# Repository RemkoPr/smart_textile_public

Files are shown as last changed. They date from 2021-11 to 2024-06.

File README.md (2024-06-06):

# Smart Textile [public repo]

This repo contains a manufaturing guide of and code for the smart textile featured in the MDPI paper [Modular Piezoresistive Smart Textile for State Estimation of Cloths](https://doi.org/10.3390/s22010222). Data obtained during the experiments outlined in this paper can be found on [Zenodo](https://doi.org/10.5281/zenodo.5718426).

Further information in README's in the subfolders.

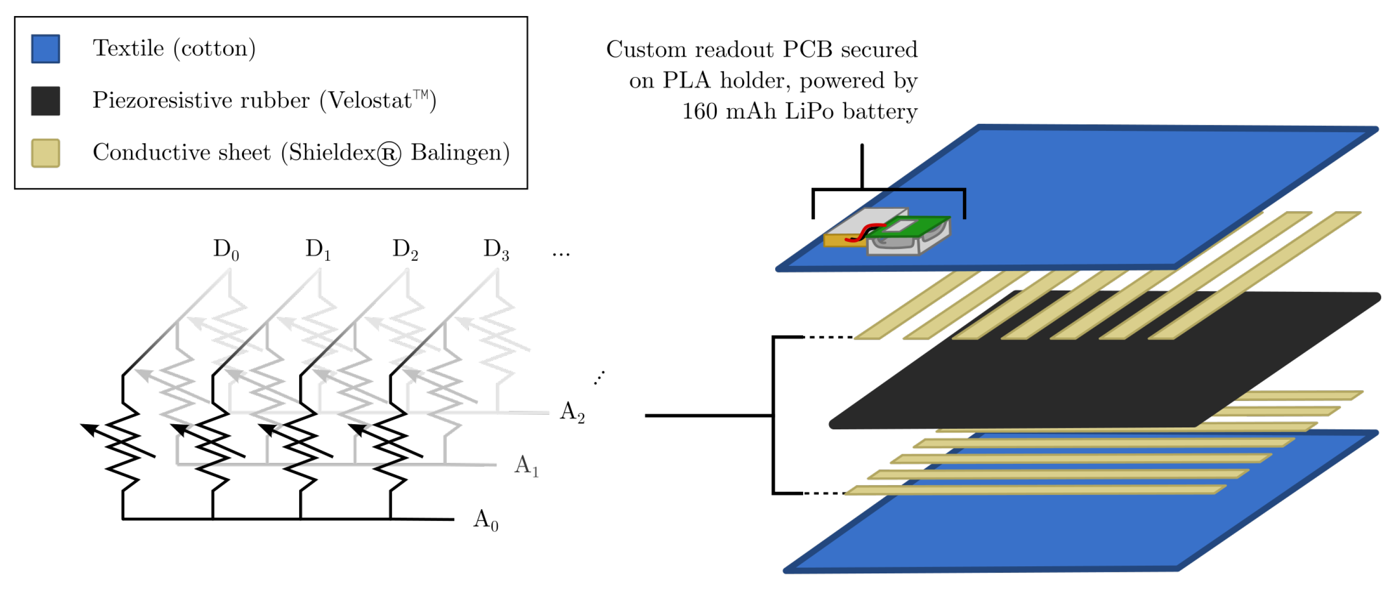
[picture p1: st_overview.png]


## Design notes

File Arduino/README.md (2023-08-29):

# Flashing the firmware

First, the smart textile PCB board must be installed to the Arduino IDE. Do this by installing the [IDLab-AIRO Boards package](https://github.com/RemkoPr/airo-nrf52840-boards/tree/main).

Once the Arduino IDE can compile sketches for the smart textile PCB, open pcb_firmware.ino and export a compiled binary.
Flashing of the PCB is done through the serial wire debug (SWD) protocol using a [JLink EDU Mini](https://www.segger.com/products/debug-probes/j-link/models/j-link-edu-mini/).
When flashing, it is recommended to use .hex files, so that you don't have to worry about the start address. Should this not be possible, use .bin files.
When reflashing the [bootloader](https://github.com/arduino/ArduinoCore-mbed/tree/master/bootloaders/nano33ble) using a .bin file, do this at address 0x00000000.
When only flashing a compiled sketch using a .bin file, do this at address 0x00010000.

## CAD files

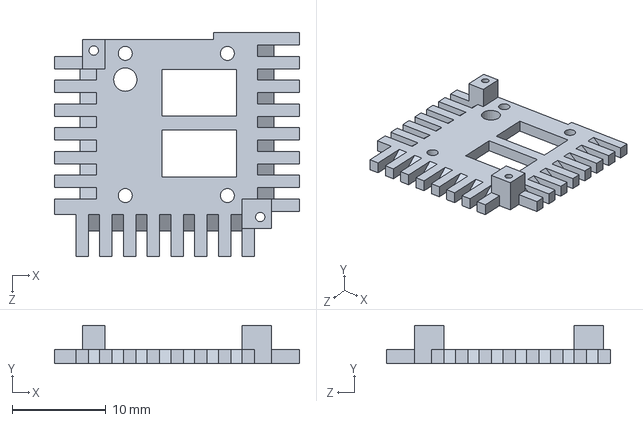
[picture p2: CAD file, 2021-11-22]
Solidworks/pcb_holder_mirrored.SLDPRT
26.2 x 4.10 x 23.9 mm

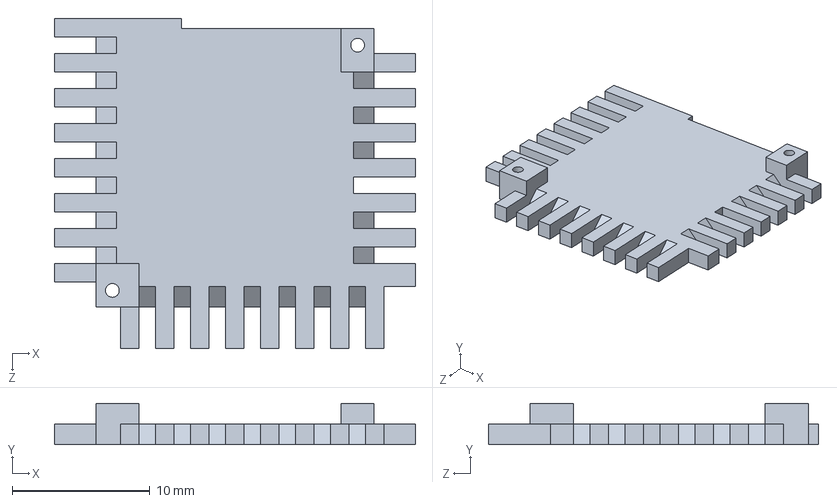
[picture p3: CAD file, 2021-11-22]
Solidworks/pcb_holder.SLDPRT
26.2 x 3.00 x 23.9 mm

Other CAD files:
Solidworks/pcb_holder.STL
Solidworks/pcb_holder_mirrored.STL

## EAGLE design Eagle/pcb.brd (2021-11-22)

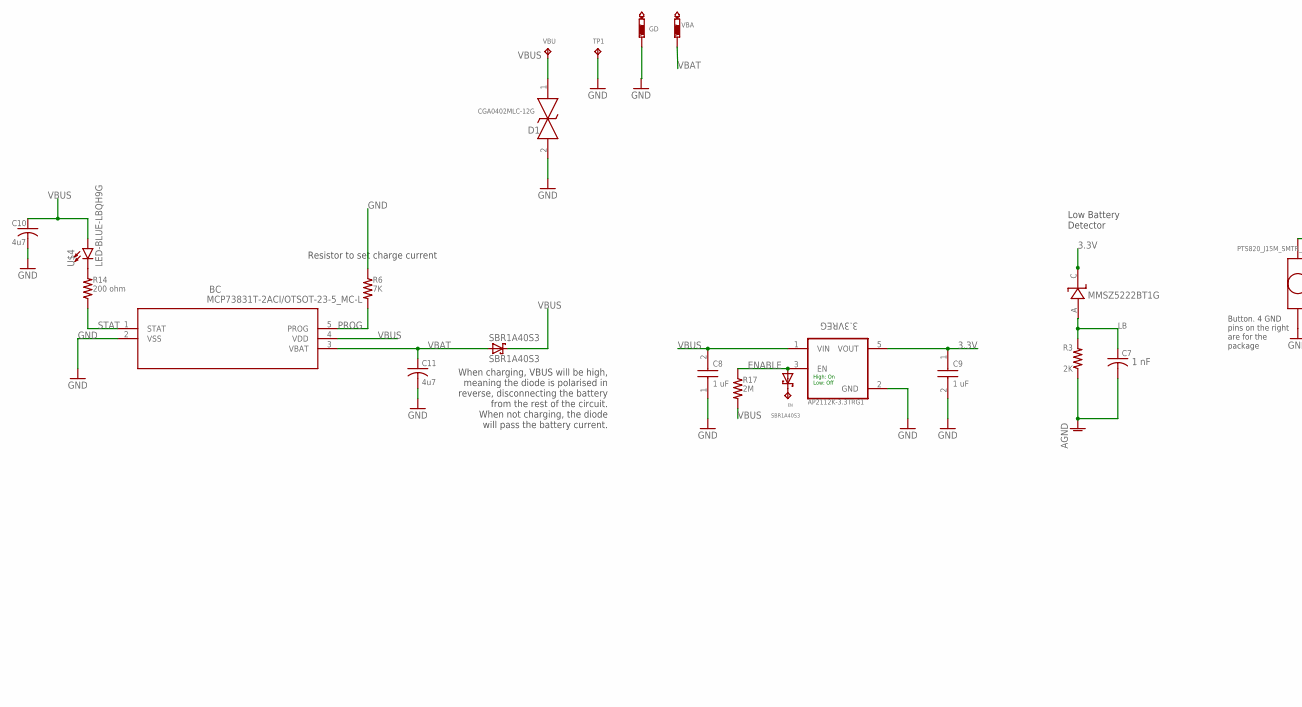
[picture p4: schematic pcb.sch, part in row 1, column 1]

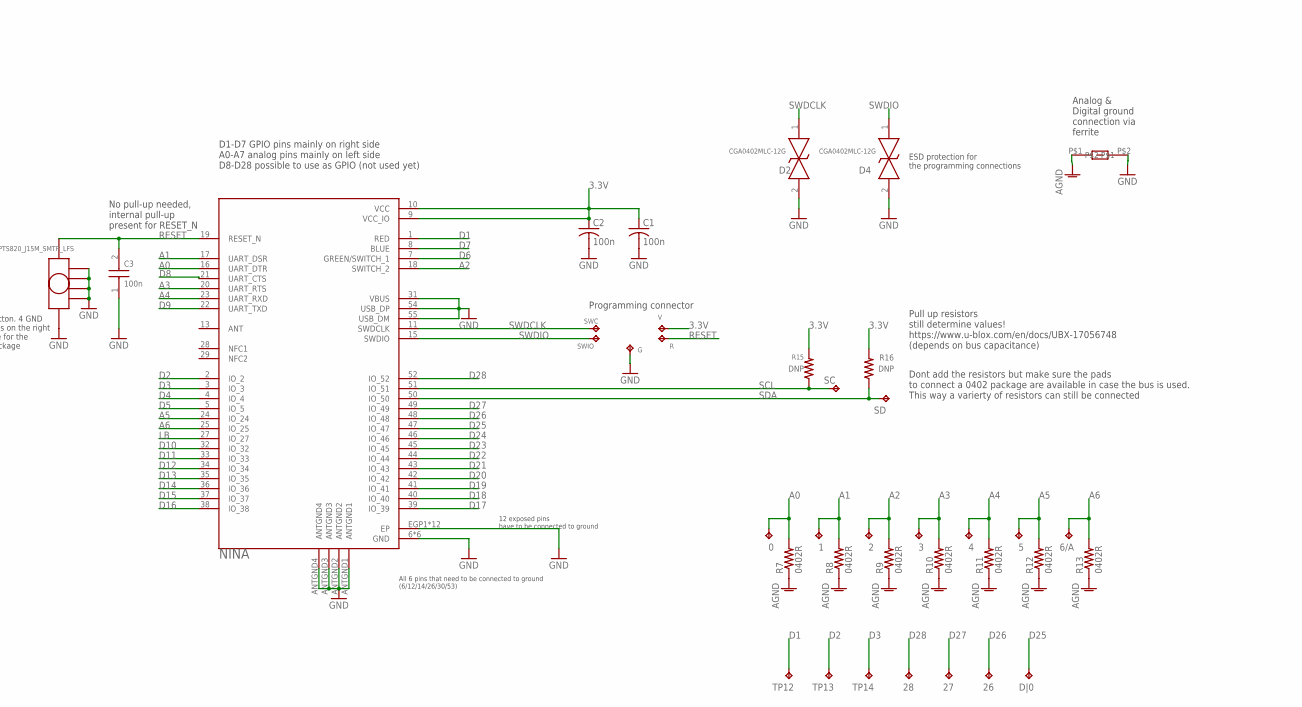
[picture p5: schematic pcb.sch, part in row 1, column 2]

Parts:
0, 1, 2, 3, 4, 5, 6/A, 26, 27, 28: CUSTOM_HOLE1; CUSTOM_HOLE
3.3VREG: AP2112K-3.3TRG1; SOT95P285X140-5N
BC: MCP73831T-2ACI/OTSOT-23-5_MC-L; SOT-23-5_MC-L
BUTTON: PTS820_J15M_SMTR_LFS; PTS820_J15
C1, C2: 100n; C0402
C3: 100n; CAPC1005X33N
C7: 1 nF; C0402
C8, C9: 1 uF; CAPC1005X33N
C10, C11: 4u7; C0402
D1, D2, D4: CGA0402MLC-12G; CGA0402MLC12G
D|0: CUSTOM_HOLE1; CUSTOM_HOLE
EN: CUSTOM_HOLE1; CUSTOM_HOLE
G: TPB1,27; B1,27
GD: PTR1TP18R; TP18R
MMSZ5222BT1G: MMSZ5222BT1G; SOD−123
R: TPB1,27; B1,27
R3: 2K; RESC1005X40N
R6: 7K; RESC1005X40N
R7, R8, R9, R10, R11, R12, R13: 0402R; RESC1005X40N
R14: 200 ohm; RESC1005X40N
R15, R16: DNP; RESC1005X40N
R17: 2M; RESC1005X40N
SBR1A40S3: SBR1A40S3; SOD323
SC: CUSTOM_HOLE1; CUSTOM_HOLE
SD: CUSTOM_HOLE1; CUSTOM_HOLE
SWC: TPB1,27; B1,27
SWIO: TPB1,27; B1,27
TP1, TP12, TP13, TP14: CUSTOM_HOLE1; CUSTOM_HOLE
U1: NINA; XCVR_NINA-B306
U$2: SBR1A40S3; SOD323
U$4: LED-BLUE-LBQH9G; LBQH9G-0402
U$5: BLM18KG121WH1D; 0603
V: TPB1,27; B1,27
VBA: PTR1TP18R; TP18R
VBU: CUSTOM_HOLE1; CUSTOM_HOLE

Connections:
3.3V: 3.3VREG.5 (VOUT), C1.1, C2.1, C9.1, MMSZ5222BT1G.C, R15.2, R16.2, U1.9 (VCC_IO), U1.10 (VCC), V.TP
A0: 0.P$1, R7.2, U1.16 (UART_DTR)
A1: 1.P$1, R8.2, U1.17 (UART_DSR)
A2: 2.P$1, R9.2, U1.18 (SWITCH_2)
A3: 3.P$1, R10.2, U1.20 (UART_RTS)
A4: 4.P$1, R11.2, U1.23 (UART_RXD)
A5: 5.P$1, R12.2, U1.24 (IO_24)
A6: 6/A.P$1, R13.2, U1.25 (IO_25)
AGND: C7.2, R3.1, R7.1, R8.1, R9.1, R10.1, R11.1, R12.1, R13.1, U$5.P$1
D1: TP12.P$1, U1.1 (RED)
D2: TP13.P$1, U1.2 (IO_2)
D3: TP14.P$1, U1.3 (IO_3)
D4: U1.4 (IO_4)
D5: U1.5 (IO_5)
D6: U1.7 (GREEN/SWITCH_1)
D7: U1.8 (BLUE)
D8: U1.21 (UART_CTS)
D9: U1.22 (UART_TXD)
D10: U1.32 (IO_32)
D11: U1.33 (IO_33)
D12: U1.34 (IO_34)
D13: U1.35 (IO_35)
D14: U1.36 (IO_36)
D15: U1.37 (IO_37)
D16: U1.38 (IO_38)
D17: U1.39 (IO_39)
D18: U1.40 (IO_40)
D19: U1.41 (IO_41)
D20: U1.42 (IO_42)
D21: U1.43 (IO_43)
D22: U1.44 (IO_44)
D23: U1.45 (IO_45)
D24: U1.46 (IO_46)
D25: D|0.P$1, U1.47 (IO_47)
D26: 26.P$1, U1.48 (IO_48)
D27: 27.P$1, U1.49 (IO_49)
D28: 28.P$1, U1.52 (IO_52)
ENABLE: 3.3VREG.3 (EN), R17.1, U$2.A
GND: 3.3VREG.2 (GND), BC.2 (VSS), BUTTON.1, BUTTON.P$1, BUTTON.P$2, BUTTON.P$3, BUTTON.P$4, C1.2, C2.2, C3.1, C8.1, C9.2, C10.2, C11.2, D1.2, D2.2, D4.2, G.TP, GD.TP, R6.1, TP1.P$1, U1.6 (GND), U1.12 (GND), U1.14 (GND), U1.26 (GND), U1.30 (GND), U1.31 (VBUS), U1.53 (GND), U1.54 (USB_DP), U1.55 (USB_DM), U1.ANTGND1, U1.ANTGND2, U1.ANTGND3, U1.ANTGND4, U1.EGP1 (EP), U1.EGP2 (EP), U1.EGP3 (EP), U1.EGP4 (EP), U1.EGP5 (EP), U1.EGP6 (EP), U1.EGP7 (EP), U1.EGP8 (EP), U1.EGP9 (EP), U1.EGP10 (EP), U1.EGP11 (EP), U1.EGP12 (EP), U$5.P$2
LB: C7.1, MMSZ5222BT1G.A, R3.2, U1.27 (IO_27)
unnamed: R14.2, U$4.C
unnamed: EN.P$1, U$2.C
PROG: BC.5 (PROG), R6.2
RESET: BUTTON.2, C3.2, R.TP, U1.19 (RESET_N)
SCL: R15.1, SC.P$1, U1.51 (IO_51)
SDA: R16.1, SD.P$1, U1.50 (IO_50)
STAT: BC.1 (STAT), R14.1
SWDCLK: D2.1, SWC.TP, U1.11 (SWDCLK)
SWDIO: D4.1, SWIO.TP, U1.15 (SWDIO)
VBAT: BC.3 (VBAT), C11.1, SBR1A40S3.A, VBA.TP
VBUS: 3.3VREG.1 (VIN), BC.4 (VDD), C8.2, C10.1, D1.1, R17.2, SBR1A40S3.C, U$4.A, VBU.P$1

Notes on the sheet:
Low Battery Detector
High: On Low: Off
When charging, VBUS will be high, meaning the diode is polarised in reverse, disconnecting the battery from the rest of the circuit. When not charging, the diode will pass the battery current.
Resistor to set charge current
D1-D7 GPIO pins mainly on right side A0-A7 analog pins mainly on left side D8-D28 possible to use as GPIO (not used yet)
12 exposed pins have to be connected to ground
All 6 pins that need to be connected to ground (6/12/14/26/30/53)
Pull up resistors still determine values! https://www.u-blox.com/en/docs/UBX-17056748 (depends on bus capacitance)
Dont add the resistors but make sure the pads to connect a 0402 package are available in case the bus is used. This way a varierty of resistors can still be connected
No pull-up needed, internal pull-up present for RESET_N
Programming connector
Button. 4 GND pins on the right are for the package
ESD protection for the programming connections
Analog & Digital ground connection via ferrite

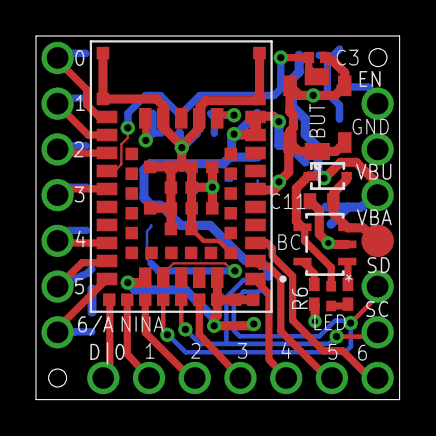
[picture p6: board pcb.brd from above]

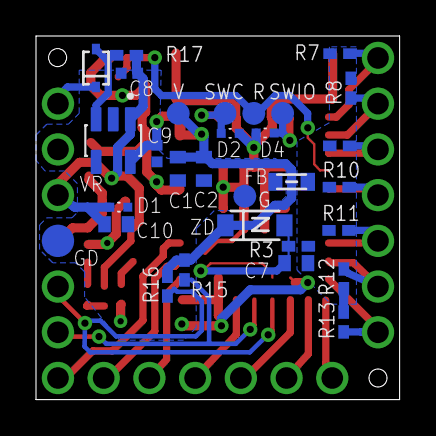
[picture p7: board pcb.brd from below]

Board: 2 copper layers, 20.2 x 20.2 mm, 59 parts (31 on the bottom side), 30 nets.

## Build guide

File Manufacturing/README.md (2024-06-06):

### Materials list
- **Conductive thread** Agsis Lite, Lyofill 166 or ["matt color half soft aluminium alloy"](https://bart-francis.be/en/10-50-100-metal/matt-color-half-soft-aluminium-alloy-45-gram-250mt/a-3113-50)
- **Conductive sheet** Shieldex Balingen
- **TPU** Bemis 3914, 100µm thick

### Additional notes
Instead of using SMD solder paste for the connection between thread and PCB, we may also suggest RS Pro Silver Paint and e.g. hot glue.

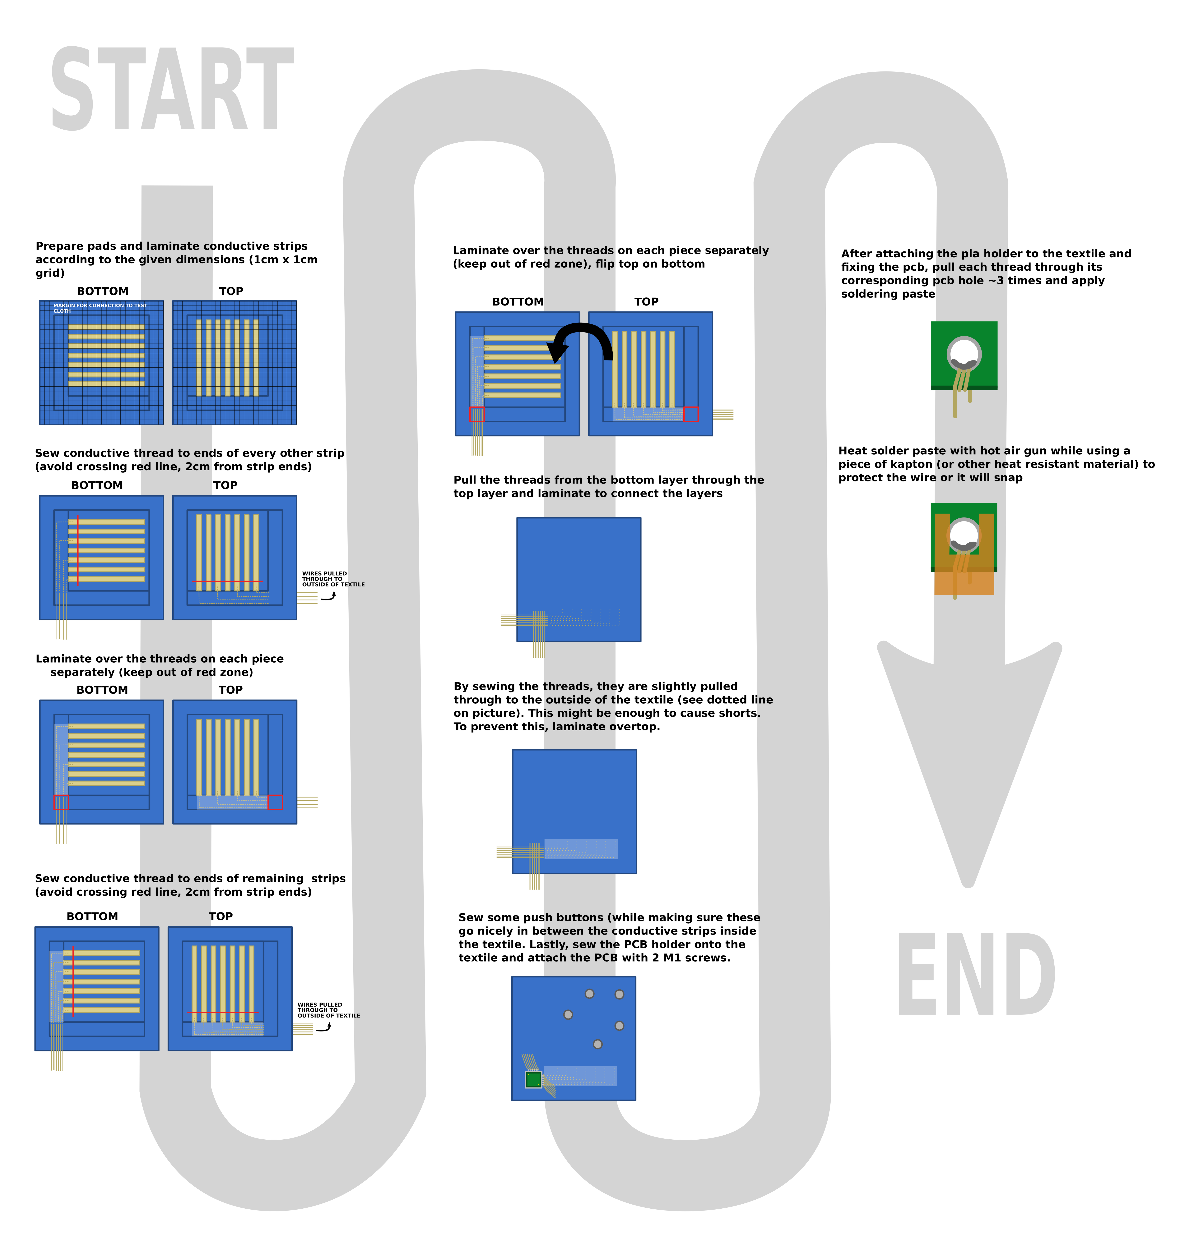
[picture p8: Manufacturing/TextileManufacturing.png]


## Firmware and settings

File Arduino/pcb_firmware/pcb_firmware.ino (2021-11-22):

/*  
 *  BEFORE FLASHING A PCB: 
 *  Make sure PCB_NAME is correct,
 *  the name is supposed to reflect the mark with which the physical PCB is distinguished. 
 */

#include <ArduinoBLE.h>

#define PCB_NAME "Smart Textile PCB [green]"
#define BLE_UUID_DATA_SERV      "ECBA" //16b UUIDs needed for compatibility with Blatann lib (python)
#define BLE_UUID_DATA_CHAR      "C130"
#define num_cols                7
#define num_rows                7
#define SERIAL                  false
#define num_data_values         num_cols * num_rows + 1 // All measuring points + a low battery indicator

using namespace std;

int D_pins[] = {0, 1, 2, 3, 4, 5, 6};
byte A_pins[] = {A0, A1, A2, A3, A4, A5, A6};
BLEService dataService( BLE_UUID_DATA_SERV );
BLECharacteristic dataCharacteristic( BLE_UUID_DATA_CHAR, BLERead | BLENotify, num_data_values, true );

uint8_t data[num_data_values];

void setup()
{
  if( SERIAL ) { Serial.begin(9600); }
  setupBleMode();

  for(int D_index=0 ; D_index < num_rows ; D_index++) {
    pinMode(D_pins[D_index], INPUT);
  }
  for(int A_index=0 ; A_index < num_cols ; A_index++) {
    pinMode(A_pins[A_index], INPUT);
  }
}


void loop()
{
  static unsigned long counter = 0;
  
  // listen for BLE peripherals to connect:
  BLEDevice central = BLE.central();

  if( SERIAL ) {
    for( int i = 0 ; i < num_data_values ; i++) { 
      Serial.print(data[i]);
      Serial.print(" ");
    }
    Serial.print("\n");
  }

  if ( central )
  {
    while ( central.connected() )
    {
      if( central.rssi() != 0 )
      {          
        readData();
        CheckBattery();
        dataCharacteristic.writeValue(data, num_data_values);
      }
    } // while connected
  } // if central
} // loop


//=================== FUNCTIONS =====================\\

void readData()
{
  int A_index, D_index;
  for(D_index=0 ; D_index < num_rows ; D_index++) {
    pinMode(D_pins[D_index], OUTPUT);
    digitalWrite(D_pins[D_index], HIGH);
    for(A_index=0 ; A_index < num_cols ; A_index++) {
      data[1 + A_index + D_index * num_rows] = analogRead(A_pins[A_index])/4.0; // Normalisation to go from 10 bit to 8 bit.
    }    
    pinMode(D_pins[D_index], INPUT);
  }
}

bool CheckBattery() 
{ 
  if( analogRead(LB)/1024.0 > 0.39 ){ // Battery is charged
    data[0] = 0;
    return false;
  }
  else { // Battery is low
    data[0] = 1;
    return true;
  }
}

bool setupBleMode() 
{  
  uint8_t i=0;
  if ( !BLE.begin() )
  {
    return false;
  }

  // set advertised local name and service UUID:
  BLE.setDeviceName( PCB_NAME );
  BLE.setLocalName( PCB_NAME );
  BLE.setAdvertisedService( dataService );

  // BLE add characteristics
  dataService.addCharacteristic( dataCharacteristic );

  // add service
  BLE.addService( dataService );
  // set the initial value for the characeristic:
  //dataCharacteristic.writeValue( 0 );
  // start advertising
  BLE.advertise();

  return true;
}

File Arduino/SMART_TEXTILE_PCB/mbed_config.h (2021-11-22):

/*
 * mbed SDK
 * Copyright (c) 2017 ARM Limited
 *
 * Licensed under the Apache License, Version 2.0 (the "License");
 * you may not use this file except in compliance with the License.
 * You may obtain a copy of the License at
 *
 * http://www.apache.org/licenses/LICENSE-2.0
 *
 * Unless required by applicable law or agreed to in writing, software
 * distributed under the License is distributed on an "AS IS" BASIS,
 * WITHOUT WARRANTIES OR CONDITIONS OF ANY KIND, either express or implied.
 * See the License for the specific language governing permissions and
 * limitations under the License.
 */

// Automatically generated configuration file.
// DO NOT EDIT, content will be overwritten.

#ifndef __MBED_CONFIG_DATA__
#define __MBED_CONFIG_DATA__

// Configuration parameters
#define ATT_NUM_SIMUL_NTF                                                     1                                                                                                // set by library:cordio
#define ATT_NUM_SIMUL_WRITE_CMD                                               1                                                                                                // set by library:cordio
#define BLE_FEATURE_EXTENDED_ADVERTISING                                      1                                                                                                // set by library:ble
#define BLE_FEATURE_GATT_CLIENT                                               1                                                                                                // set by library:ble
#define BLE_FEATURE_GATT_SERVER                                               1                                                                                                // set by library:ble
#define BLE_FEATURE_PERIODIC_ADVERTISING                                      1                                                                                                // set by library:ble
#define BLE_FEATURE_PHY_MANAGEMENT                                            1                                                                                                // set by library:ble
#define BLE_FEATURE_PRIVACY                                                   1                                                                                                // set by library:ble
#define BLE_FEATURE_SECURE_CONNECTIONS                                        1                                                                                                // set by library:ble
#define BLE_FEATURE_SECURITY                                                  1                                                                                                // set by library:ble
#define BLE_FEATURE_SIGNING                                                   1                                                                                                // set by library:ble
#define BLE_FEATURE_WHITELIST                                                 1                                                                                                // set by library:ble
#define BLE_ROLE_BROADCASTER                                                  1                                                                                                // set by library:ble
#define BLE_ROLE_CENTRAL                                                      1                                                                                                // set by library:ble
#define BLE_ROLE_OBSERVER                                                     1                                                                                                // set by library:ble
#define BLE_ROLE_PERIPHERAL                                                   1                                                                                                // set by library:ble
#define CHCI_TR_UART                                                          0                                                                                                // set by library:cordio-ll
#define CORDIO_ZERO_COPY_HCI                                                  1                                                                                                // set by library:cordio-nordic-ll
#define DM_CONN_MAX                                                           3                                                                                                // set by library:cordio
#define DM_NUM_ADV_SETS                                                       3                                                                                                // set by library:cordio
#define DM_NUM_PHYS                                                           3                                                                                                // set by library:cordio
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

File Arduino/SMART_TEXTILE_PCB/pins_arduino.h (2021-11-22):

#pragma once
#include "mbed_config.h"
#include <stdint.h>
#include <macros.h>

#ifndef __PINS_ARDUINO__
#define __PINS_ARDUINO__

// Frequency of the board main oscillator
#define VARIANT_MAINOSC (32768ul)

// Master clock frequency
#define VARIANT_MCK     (64000000ul)

// Pins
// ----

// Number of pins defined in PinDescription array
#ifdef __cplusplus
extern "C" unsigned int PINCOUNT_fn();
#endif
#define PINS_COUNT           (PINCOUNT_fn())
#define NUM_DIGITAL_PINS     (21u)
#define NUM_ANALOG_INPUTS    (7u)
#define NUM_ANALOG_OUTPUTS   (0u)

// Analog pins
// -----------
#define PIN_A0 (7u)
#define PIN_A1 (8u)
#define PIN_A2 (9u)
#define PIN_A3 (10u)
#define PIN_A4 (11u)
#define PIN_A5 (12u)
#define PIN_A6 (13u)
static const uint8_t A0  = PIN_A0;
static const uint8_t A1  = PIN_A1;
static const uint8_t A2  = PIN_A2;
static const uint8_t A3  = PIN_A3;
static const uint8_t A4  = PIN_A4;
static const uint8_t A5  = PIN_A5;
static const uint8_t A6  = PIN_A6;
#define ADC_RESOLUTION 12

// Low battery detector readout pin
#define PIN_LB (16u)
static const uint8_t LB = PIN_LB;

// Digital pins
// -----------
#define D0   0
#define D1   1
#define D2   2
#define D3   3
#define D4   4
#define D5   5
#define D6   6

// Wire
#define PIN_WIRE_SDA        (14u)
#define PIN_WIRE_SCL        (15u)

// These serial port names are intended to allow libraries and architecture-neutral
// sketches to automatically default to the correct port name for a particular type
// of use.  For example, a GPS module would normally connect to SERIAL_PORT_HARDWARE_OPEN,
// the first hardware serial port whose RX/TX pins are not dedicated to another use.
//
// SERIAL_PORT_MONITOR        Port which normally prints to the Arduino Serial Monitor
//
// SERIAL_PORT_USBVIRTUAL     Port which is USB virtual serial
//
// SERIAL_PORT_LINUXBRIDGE    Port which connects to a Linux system via Bridge library
//
// SERIAL_PORT_HARDWARE       Hardware serial port, physical RX & TX pins.
//
// SERIAL_PORT_HARDWARE_OPEN  Hardware serial ports which are open for use.  Their RX & TX
//                            pins are NOT connected to anything by default.

// Mbed specific defines
#define SERIAL_HOWMANY		0

#define SERIAL_CDC			1
#define HAS_UNIQUE_ISERIAL_DESCRIPTOR
#define BOARD_VENDORID		0x2342
#define BOARD_PRODUCTID		0x805b
#define BOARD_NAME			"SMART_TEXTILE_PCB"

#define DFU_MAGIC_SERIAL_ONLY_RESET   0xb0

#define I2C_SDA				(digitalPinToPinName(PIN_WIRE_SDA))
#define I2C_SCL				(digitalPinToPinName(PIN_WIRE_SCL))

#define digitalPinToPort(P)		(digitalPinToPinName(P)/32)

#ifdef SERIAL_CDC
	uint8_t getUniqueSerialNumber(uint8_t* name);
#endif
void _ontouch1200bps_();

#endif //__PINS_ARDUINO__

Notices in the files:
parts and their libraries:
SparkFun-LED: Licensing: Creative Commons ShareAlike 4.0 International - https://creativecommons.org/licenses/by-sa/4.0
